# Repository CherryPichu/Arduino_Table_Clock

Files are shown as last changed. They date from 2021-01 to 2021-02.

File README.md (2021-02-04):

# Arduino_Table_Clock
아두이노 스마트 탁상시계 프로젝트 / Arduino Smart Desk Clock Project

** 강원FABLAB (한림대학교 산업협력단) Fab Lab Gangwon Making project - 디지털 장비를 활용한 메이킹 프로젝트

자취방 아이템 스마트 탁상시계  (1월 18일 ~ 1월 29일) 2주
------------------------------

**[유튜브 동영상](https://youtu.be/rYzuArcCpqY)**

아두이노 스마트 탁상시계 프로젝트 (https://youtu.be/rYzuArcCpqY)

<hr>
**작동 설명** 

자취방 혹은 기숙사에서 온도와 습도 그리고 조도 데이터를 눈으로 직접 확인하기 어렵다.

이 프로젝트는 거주공간에서 시계역활을 해주는 동시에 자취방 **온도, 습도, 조도** 데이터를 25초 간격으로 

**SD카드에 저장**하고 **API 서버**에 데이터를 보낸다.

이러한 데이터를 꾸준히 쌓아서 파이썬을 통해 **시각화를 거치면 거주 공간의 문제점을 파악할 수 있다.**

데이터는 SD카드와 인터넷 서버를 통해 이중으로 저장하는 만큼 어느 상황에서도 작동을 보장한다.

**기본 모드**

기본 모드

**기본 모드** 에서는 실시간으로 시간을 확인 할 수 있다.

별다른 조작이 없다면 기본 모드를 유지한다.

**상세 모드**

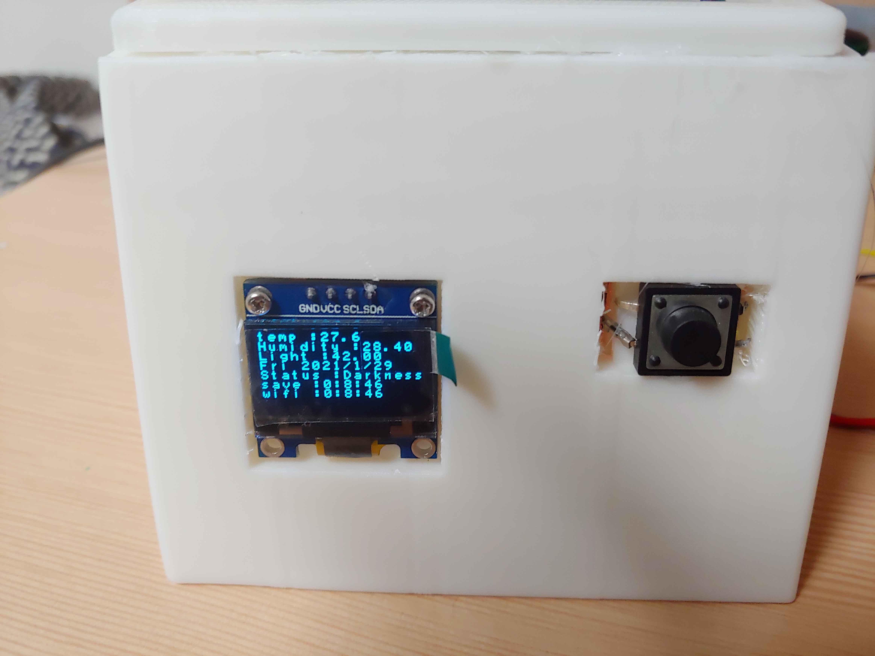
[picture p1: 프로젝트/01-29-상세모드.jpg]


상세 모드는 전면의 버튼을 클릭했을 때 4초간 보여준다.

상세 모드에서 보여줄 수 있는 정보은 하단의 내용과 같다.

\- temp : 현재 온도

\- Humidity : 현재 습도

\- 날짜

\- 현재 상태(빛) 5단계

 Very Bright – 매우 밝음

 Bright – 밝음

 Slight darkness – 약간 어두움

 Darkness – 어두움

 Very dark – 매우 어두움

\- save : 마지막 sd 저장 시간

\- wifi : 마지막 와이파이 저장 시간

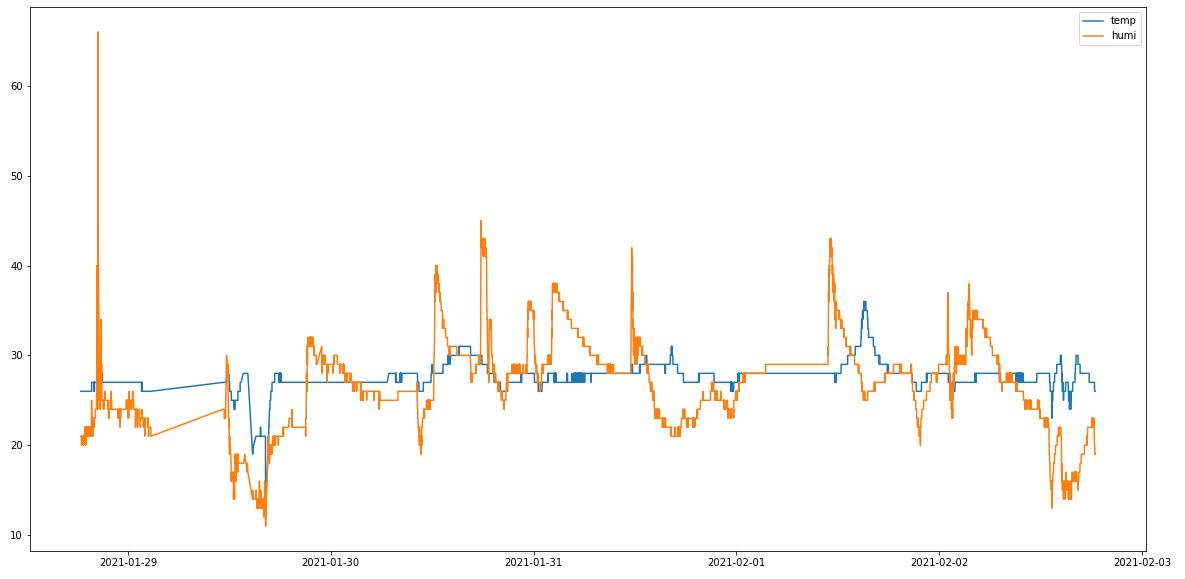
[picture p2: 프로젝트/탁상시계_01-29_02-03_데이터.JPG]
온습도 데이터


**[2021-01-29일~ 2021년 02월 03일 데이터 그래프 (온도 temp / 습도 humi)]**

실제로 저장받은 5일 동안의 데이터를 시각화를 시키면 알 수 있듯이.

습도와 온도는 상관 관계가 있다.

이는 생활 패턴과 관련이 있는데 화장실을 이용하고 문을 열어두면 굉장히 많은 습도가 방을 채운다.

또 동시에 온도가 높아지는 것을 확인할 수 있다.

창문을 열면은 추운 바람이 들어오면서 온도와 습도는 극격하게 내려가는 것을 확인할 수 있다.

습도는 20~35 사이로 적절한 습도를 유지하고 있음을 보여준다.(습도는 20 이하로 내려가지 않는 것이 좋다.)

상세 모드

**평균 온도**는 **27.5도**이고

**평균 습도**는 **27%** 이다.

데이터는 꾸준히 온라인과 SD카드에 저장되고 있다.

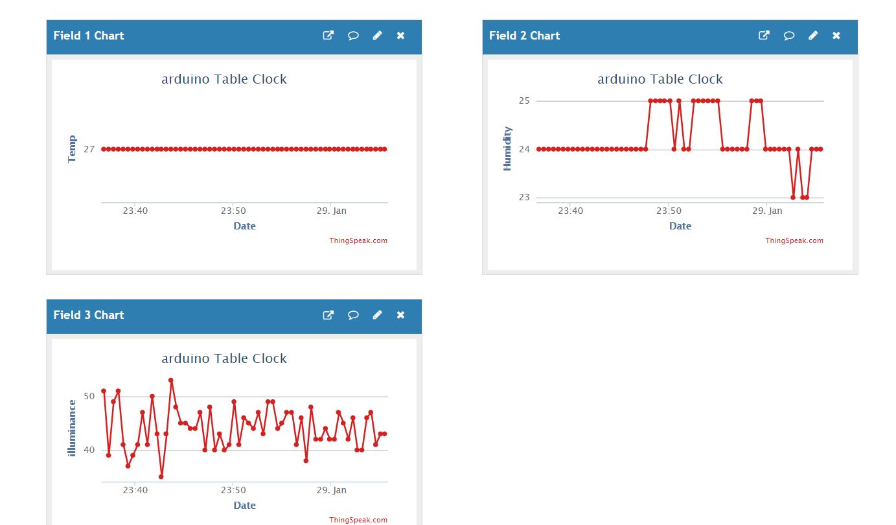
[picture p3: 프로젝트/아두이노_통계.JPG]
thingspeak.com


[thingspeak 온라인 데이터](https://thingspeak.com/channels/1291441)

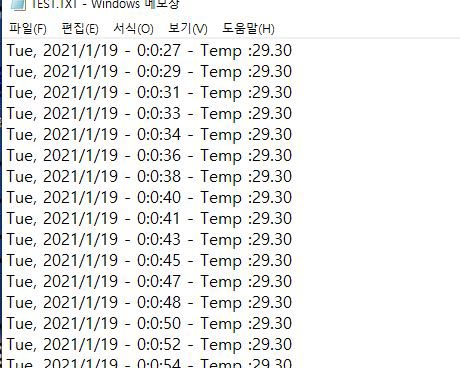
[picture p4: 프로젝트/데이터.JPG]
sd카드 저장 데이터


[SD카드 데이터]

마지막으로 프로젝트 후반에 추가된 조도 데이터는 사용자의 잠자는 시간과 패턴 등을 분석하기 좋다.

조도 데이터는 0(불빛 없음) ~ 1000 이상으로 데이터 편차가 크므로 log를 취해서 편차를 줄이면 조금더 유의미한 데이터를 얻을 수 있다.

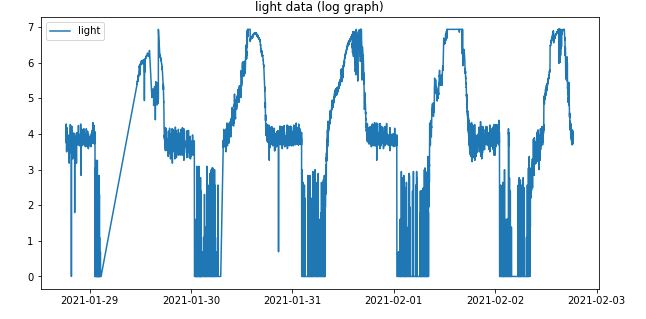
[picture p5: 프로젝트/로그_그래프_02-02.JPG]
조도 데이터


<hr>

- **내부 부품**

1. 아두이노 NANO 33 IOT
2. RTC DS3231 모듈
3. 0.96인치 128x64 OLED LCD 모듈
4. SD 카드 리더기 모듈
5. TEMT6000 조도 센서 모듈
6. [YwRobot] AM2302 (DHT22) 고정밀 온습도 센서 모듈

- 참고 사이트
  아두이노 Nano 33 IOT  
  https://fishpoint.tistory.com/5251
  RTC 모듈
  https://deneb21.tistory.com/327
  0.96인치 128x64 OLED LCD 모듈
  https://orasman.tistory.com/297

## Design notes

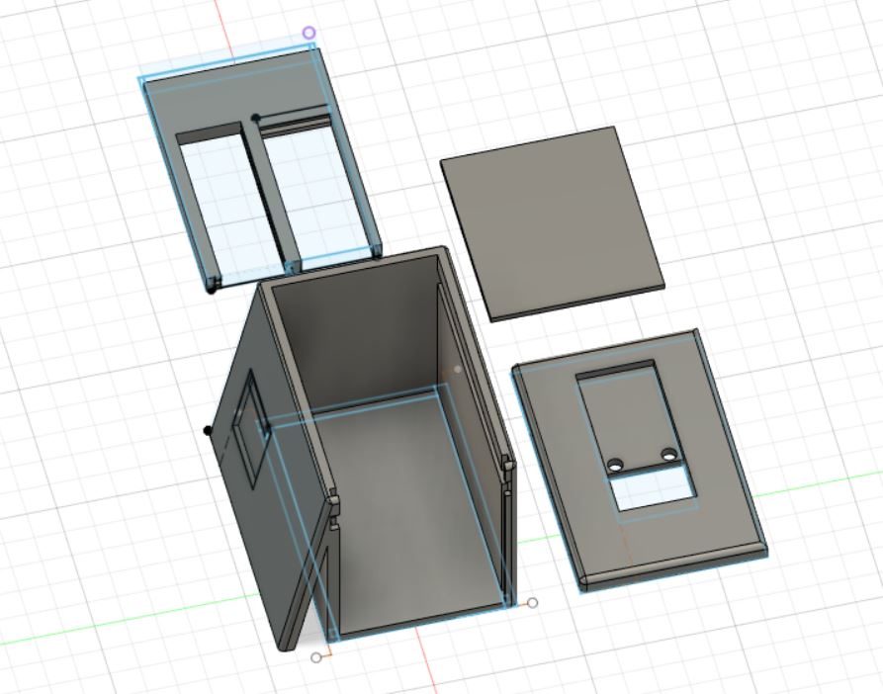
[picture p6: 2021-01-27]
프로젝트/21-01-22 모델링.JPG

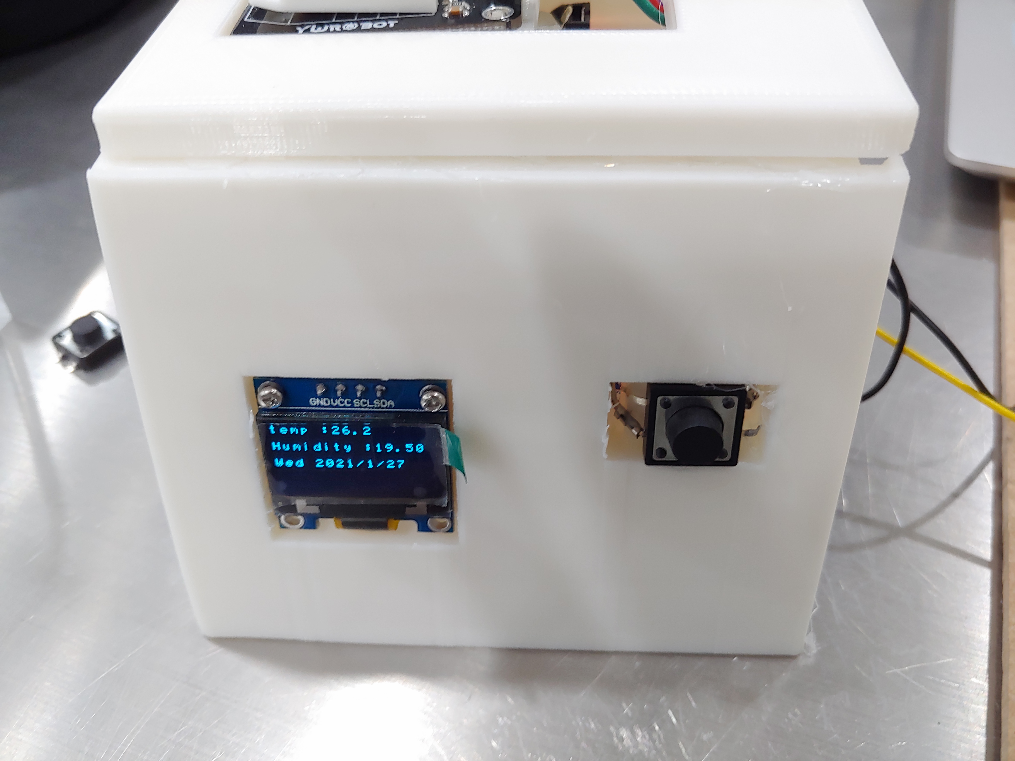
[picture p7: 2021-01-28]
프로젝트/01-27-탁상시계2.jpg

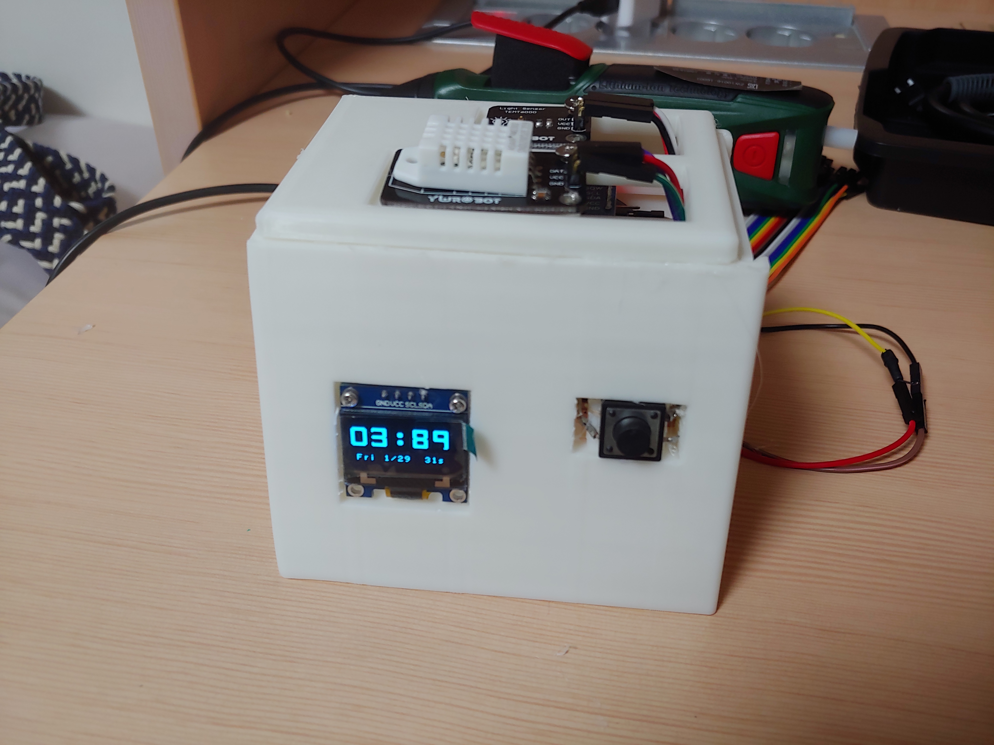
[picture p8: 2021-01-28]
프로젝트/01-29-기본-모드.jpg

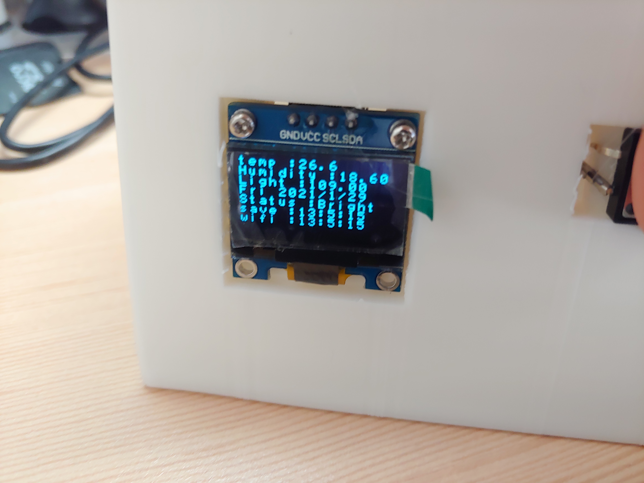
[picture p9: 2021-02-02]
프로젝트/화면.jpg

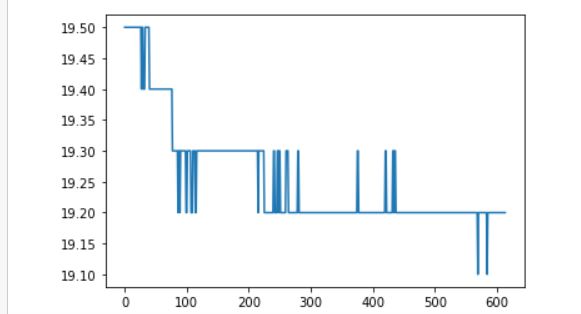
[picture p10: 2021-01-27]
프로젝트/온도 분석 _ 한림 메이커 스페이스 (10분).JPG

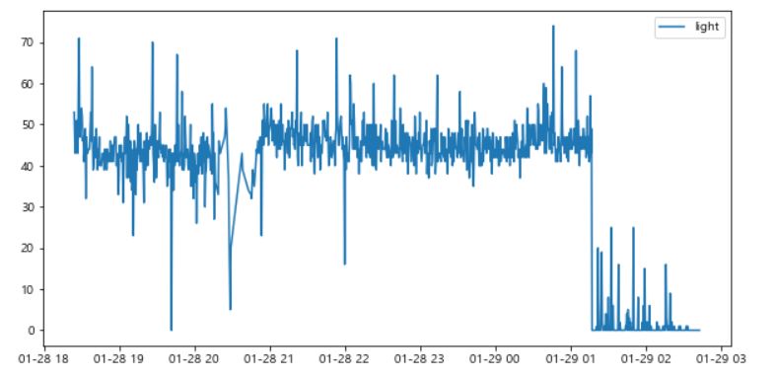
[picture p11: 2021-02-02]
프로젝트/light.JPG

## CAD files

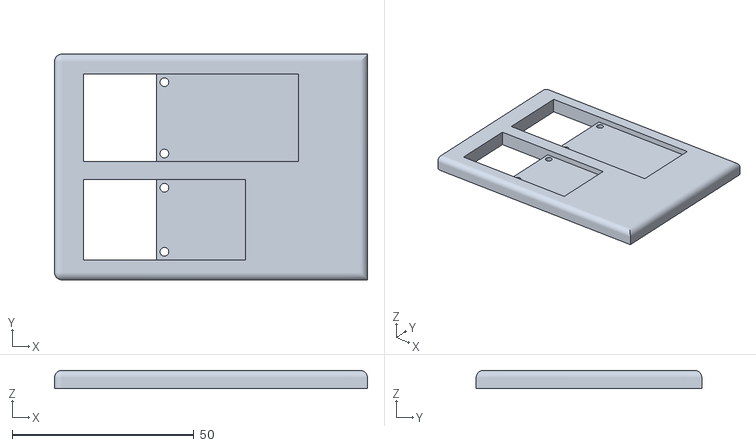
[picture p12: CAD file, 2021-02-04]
stl 파일/roof.stl
86.0 x 62.0 x 5.00

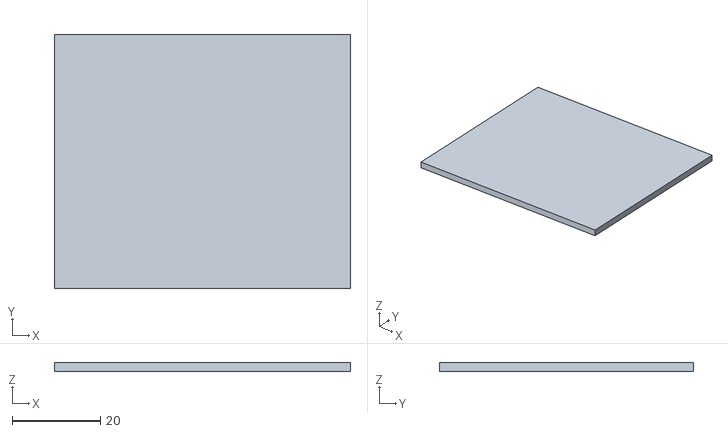
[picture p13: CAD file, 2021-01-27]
프로젝트/door.stl
67.0 x 57.6 x 2.00

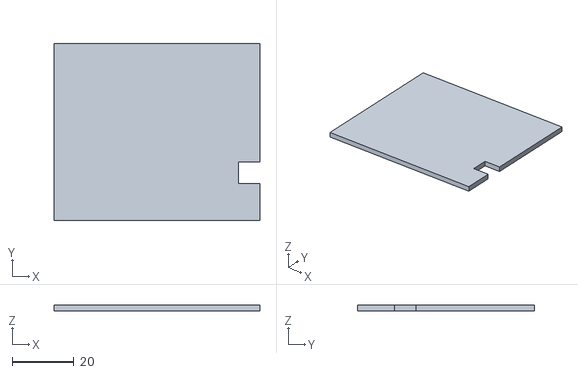
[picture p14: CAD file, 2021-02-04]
stl 파일/door.stl
67.0 x 57.6 x 2.00

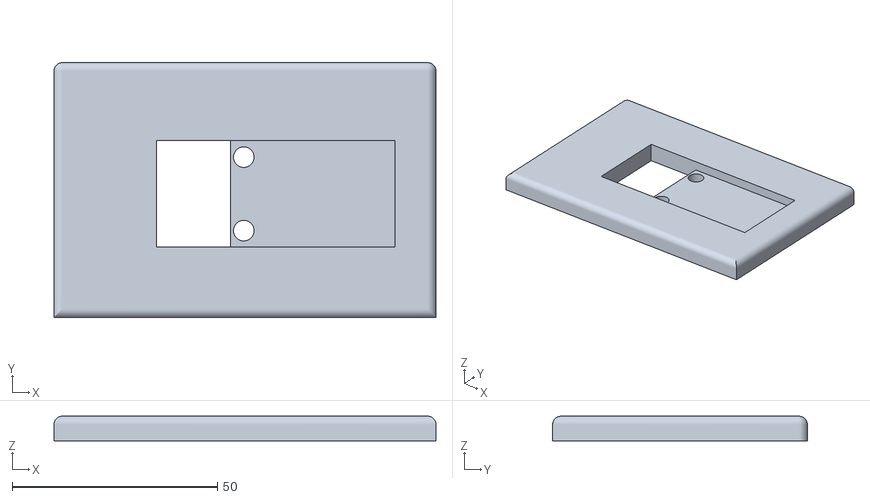
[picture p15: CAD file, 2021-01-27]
프로젝트/지붕.stl
93.0 x 62.0 x 6.00

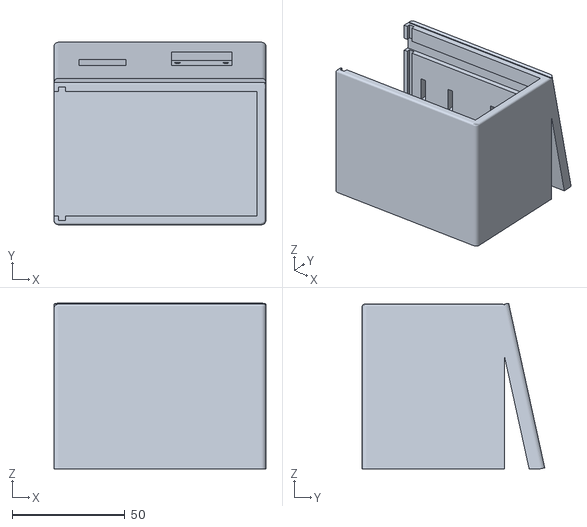
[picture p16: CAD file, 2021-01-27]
stl 파일/01_26_TABLE.stl
94.0 x 81.0 x 73.4

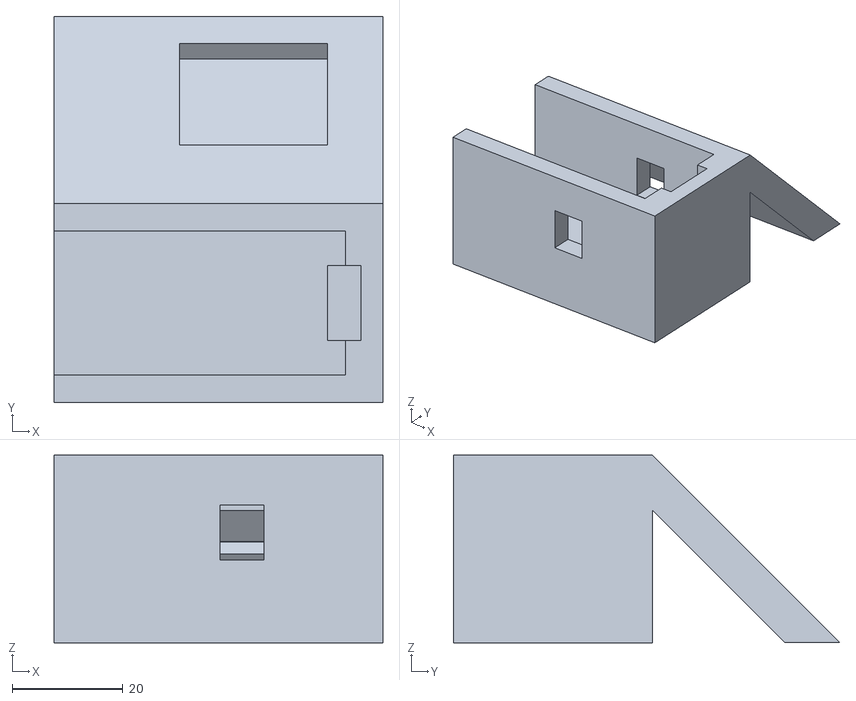
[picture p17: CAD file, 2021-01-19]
프로젝트/탁상시계_허남정.stl
59.5 x 69.9 x 34.0

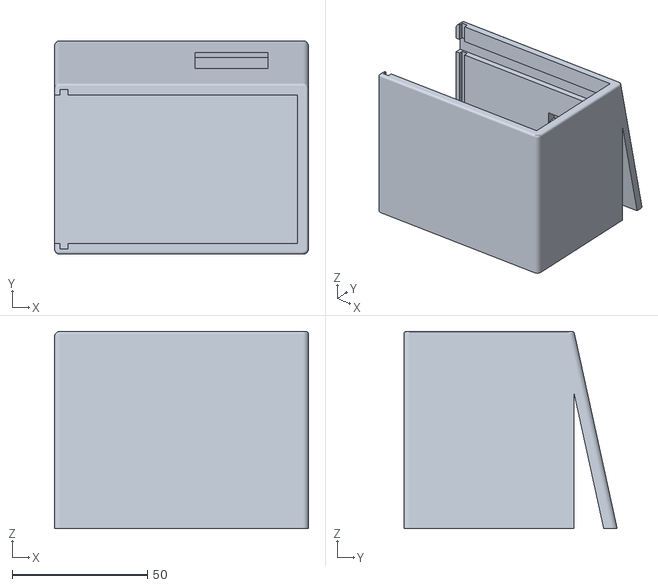
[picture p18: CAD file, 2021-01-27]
stl 파일/Table_clock.stl
94.0 x 79.0 x 73.0

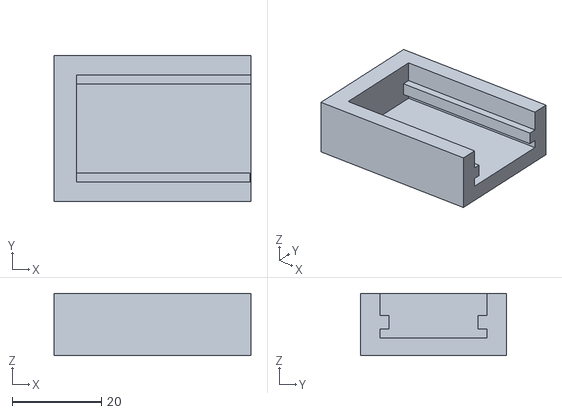
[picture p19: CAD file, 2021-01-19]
프로젝트/센서 케이스.stl
44.2 x 32.8 x 14.0

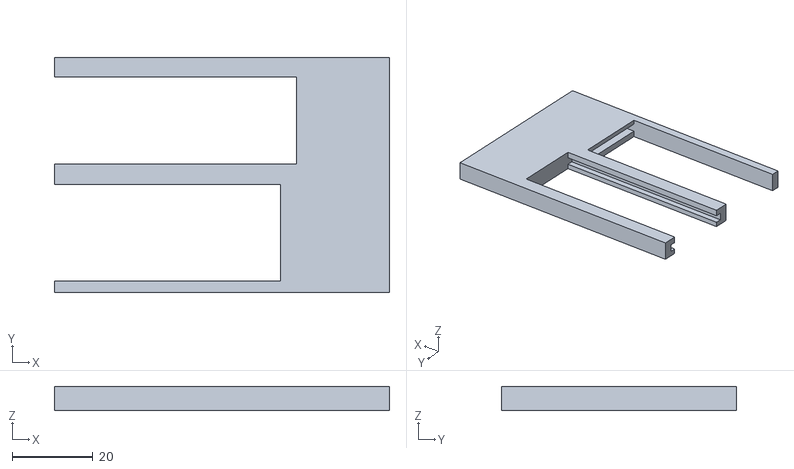
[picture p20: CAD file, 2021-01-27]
stl 파일/sensor.stl
83.0 x 58.2 x 6.00

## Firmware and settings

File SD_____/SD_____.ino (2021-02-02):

#include "DHT.h"
#include <SD.h>
#include <SPI.h>
#include <Wire.h>
#include <OzOLED.h>
#include <math.h>
#include <WiFiNINA.h>

int CS_PIN = 10;
int Sensor0 = 0;
String Data = "";
int count_down = 0; // sd카드 저장 주기 시간 계산해주는 변수(20)
int screen_change = 0; // 스크린 바뀔때 시간 세주는 변수
String last_save = ""; // 마지막으로 저장 시기
String last_wifi = ""; // 마지막으로 와이파이 통신시기

char ssid[] = "8-1324";        // your network SSID (name)  8-1324  Cherry
char pass[] = "";    // your network password (use for WPA, or use as key for WEP)
char server[] = "api.thingspeak.com";
int keyIndex = 0;
int status = WL_IDLE_STATUS; // wifi 추가
WiFiSSLClient client;

#define DHTPIN 2        // SDA 핀의 설정
#define DHTTYPE DHT22   // DHT22 (AM2302) 센서종류 설정
DHT dht(DHTPIN, DHTTYPE);

#include <Wire.h>
 
#define DS3231_I2C_ADDRESS 104
short seconds, minutes, hours, day, date, month, year;
char weekDay[4];
 
short tMSB, tLSB;
float temp3231;

File myFile;
#define LIGHTPIN A0 //Ambient light sensor reading
void setup() {
  
//  send_api();
  Serial.begin(115200); // 115200 9600
  delay(2000); // 버그 수정 딜레이를 줘야만 전원을 동시에 공급했을때 작동하는 듯?
  pinMode(4, OUTPUT); // 스위치(버튼)
  pinMode(5, INPUT_PULLUP);
  pinMode(LIGHTPIN, INPUT); //조도 센서
  OzOled.init();  //initialze Eduino OLED display
  OzOled.printString("Hello!");
  // put your setup code here, to run once:
  wifi_init();
  
  pinMode(CS_PIN, OUTPUT);
  dht.begin();
  Wire.begin();
  initalizeSD();
  OzOled.clearDisplay();
}

void initalizeSD(){
  Serial.println("Interalizing SD card..");
  pinMode(CS_PIN,OUTPUT);
  if(SD.begin()){
    Serial.println("SD Card is ready to use.");
  }else {
    Serial.println("SD Card initalization failed");
    OzOled.clearDisplay();
    OzOled.printString("SD Card", 0, 0);
    OzOled.printString("initalization failed", 0, 1);
    delay(3000);
    return;
  }
  return;
}
float get_light(){
  float reading = analogRead(LIGHTPIN); 
  return reading;
}
void wifi_init(){ // wifi 추가
  if (WiFi.status() == WL_NO_MODULE) {
    Serial.println("Communication with WiFi module failed!");
    OzOled.printString("Communication with WiFi module failed!", 0,1);
    // don't continue
    while (true);
  }
  while (status != WL_CONNECTED) {
    Serial.print("Attempting to connect to SSID: ");
    OzOled.printString("Attempting to connect to SSID: ",0,2);
    Serial.println(ssid);
    // Connect to WPA/WPA2 network. Change this line if using open or WEP network:
    status = WiFi.begin(ssid, pass);

    // wait 10 seconds for connection:
    delay(10000);
  }
  Serial.println("Connected to wifi");
  OzOled.printString("Connected to wifi",0,4);
  printWiFiStatus();
   String fv = WiFi.firmwareVersion();
    if (fv < WIFI_FIRMWARE_LATEST_VERSION) {
    Serial.println("Please upgrade the firmware");
  }
  Serial.println("\nStarting connection to server...");
  OzOled.printString("Starting connection to server...",0,5);
  // if you get a connection, report back via serial:
  OzOled.clearDisplay();
}
void send_api(int temp, int humidity, float light) { // wifi 추가

  if (client.connect(server, 443)) {
    Serial.println("connected to server");
//    OzOled.printString("connected to server",0,6);
    // Make a HTTP request:
    client.println("GET /update?api_key=I1IPO6UY6WQG4IN8&field1="+String(temp)+"&field2="+String(humidity)+"&field3=" + String(light));
    client.println("Host: api.thingspeak.com");
    client.println("Connection: close");
    client.println();
    last_wifi = String(hours) + ":" +String(minutes) + ":" + String(seconds);
  }
}
void TestWiFiConnection()
//test if always connected
{
 int StatusWiFi=WiFi.status();
 if(StatusWiFi==WL_CONNECTION_LOST || StatusWiFi==WL_DISCONNECTED || StatusWiFi==WL_SCAN_COMPLETED) //if no connection
 {
  WiFi.end(); // WiFi를 종료한다.
  WiFiConnect(); //if my SSID is present, connect
 }
}
void WiFiConnect()
//connect to my SSID
{
 status= WL_IDLE_STATUS;
 while(status!=WL_CONNECTED)
 {
    OzOled.printString("try to connect..",1, 0, 15);
   status = WiFi.begin(ssid,pass);
   delay(2000);
  }
  OzOled.printString("               ",1, 0, 20);
}


void loop() {
  float light  = get_light();
  float humidity = dht.readHumidity();
  float temp = dht.readTemperature();
  String light_status = "";
  if(light > 140) {
      light_status = "Very bright"; 
    }else if(light > 80 && light <= 140) {
      light_status = "Bright"; 
    }else if(light > 60 && light <= 80) {
      light_status = "Slight darkness";
    }else if(light > 30 && light <= 60) {
      light_status = "Darkness";
    }else if(light > 0 && light <= 30) {
      light_status = "Very dark";
    }
   TestWiFiConnection();
  // put your main code here, to run repeatedly:
  watchConsole();
  get3231Date();
  Data =  String(weekDay) + ", 20" + String(year) + "/" + String(month) + "/" + String(date) + "," + String(hours) + ":" + String(minutes) + ":" + 
       String(seconds) + " , Temp :" + String(temp) + " , Humidity :" + String(humidity)+", light :" + String(light);
  if(count_down == 20){
  //("20" + String(year) + "/" + String(month)+"/"+String(date) +"-info")
      String file_name = String(month)+"M"+String(date)+"D.txt";
      Serial.println(file_name);
      myFile = SD.open(file_name, FILE_WRITE);
      send_api(temp, humidity, light);
      if(myFile){
        Serial.println("File created successfully");
        last_save = String(hours) + ":" +String(minutes) + ":" + String(seconds);
      }else {
        Serial.println("Error while creating file.");
        OzOled.clearDisplay();
        OzOled.printString("Error while", 0, 0);
        OzOled.printString("creating file", 0, 1);
        delay(2000);
        OzOled.clearDisplay();
      }
    myFile.println(Data);
    myFile.close();
    count_down = 0;
  }else{
    count_down++;
  }
  
  
  Serial.println(Data);
  // 아래 코드는 기본 화면 구성 출력
  if(digitalRead(5) == LOW){ // 스위치가 눌렸을 경우
    screen_change = 5;
    OzOled.clearDisplay();
  }
  if(screen_change > 1){ // 버튼이 눌린 경우에 온도와 습도창을 보여준다.
    OzOled.printString(("temp :"+String(temp,2)).c_str(), 0 ,0,10);
    OzOled.printString(("Humidity :" + String(humidity,2)).c_str(), 0 ,1,16);
    OzOled.printString(("Light :" + String(light, 2)).c_str(), 0 ,2,16);
    OzOled.printString((String(weekDay)+" "+ "20" + String(year) + "/" + String(month)+"/"+String(date)).c_str(), 0 ,3,16);
    OzOled.printString(("Status :" + light_status).c_str(), 0 ,4,16);
    OzOled.printString(("save :" + last_save).c_str(), 0 ,5,16);
    OzOled.printString(("wifi :" + last_wifi).c_str(), 0 ,6,16);
    screen_change--;
    if(screen_change == 1){
      screen_change = 0;
      OzOled.clearDisplay();
    }
  }else{
    String str_hours = String(hours);
    String str_minutes = String(minutes);
    String str_seconds = String(seconds) + "s ";
    const char * time_hours = str_hours.c_str(); // 한글 출력 방법
    const char * time_minutes = str_minutes.c_str(); 
    const char * time_seconds = str_seconds.c_str(); 
    
    OzOled.printBigNumber(time_hours, 0, 1,3);
    OzOled.printBigNumber(":",6,1, 10);
    OzOled.printBigNumber(time_minutes, 9, 1,3);
    OzOled.printString(time_seconds,11,6, 3); //x위치 y위치 글자 수
    
    OzOled.printString((String(weekDay)+" "+ String(month)+"/"+String(date)).c_str(),1,6, 10); 

  }
  


  
  delay(1000);
}


// 10진수를 2진화 10진수인 BCD 로 변환 (Binary Coded Decimal)
short decToBcd(short val)
{
  return ( (val/10*16) + (val%10) );
}
 
void watchConsole()
{
  if (Serial.available()) {      // Look for char in serial queue and process if found
    if (Serial.read() == 84) {   //If command = "T" Set Date
//      set3231Date();
      get3231Date();
      Serial.println(" ");
    }
  }
}
 
//시간설정
// T(설정명령) + 년(00~99) + 월(01~12) + 일(01~31) + 시(00~23) + 분(00~59) + 초(00~59) + 요일(1~7, 일1 월2 화3 수4 목5 금6 토7)
// 예: T1605091300002 (2016년 5월 9일 13시 00분 00초 월요일)
void set3231Date()
{
  year    = (short) ((Serial.read() - 48) *10 +  (Serial.read() - 48));
  month   = (short) ((Serial.read() - 48) *10 +  (Serial.read() - 48));
  date    = (short) ((Serial.read() - 48) *10 +  (Serial.read() - 48));
  hours   = (short) ((Serial.read() - 48) *10 +  (Serial.read() - 48));
  minutes = (short) ((Serial.read() - 48) *10 +  (Serial.read() - 48));
  seconds = (short) ((Serial.read() - 48) * 10 + (Serial.read() - 48));
  day     = (short) (Serial.read() - 48);
 
  Wire.beginTransmission(DS3231_I2C_ADDRESS);
  Wire.write(0x00);
  Wire.write(decToBcd(seconds));
  Wire.write(decToBcd(minutes));
  Wire.write(decToBcd(hours));
  Wire.write(decToBcd(day));
  Wire.write(decToBcd(date));
  Wire.write(decToBcd(month));
  Wire.write(decToBcd(year));
  Wire.endTransmission();
}
 
 
void get3231Date()
{
  // send request to receive data starting at register 0
  Wire.beginTransmission(DS3231_I2C_ADDRESS); // 104 is DS3231 device address
  Wire.write(0x00); // start at register 0
  Wire.endTransmission();
  Wire.requestFrom(DS3231_I2C_ADDRESS, 7); // request seven shorts
 
  if(Wire.available()) {
    seconds = Wire.read(); // get seconds
    minutes = Wire.read(); // get minutes
    hours   = Wire.read();   // get hours
    day     = Wire.read();
    date    = Wire.read();
    month   = Wire.read(); //temp month
    year    = Wire.read();
       
    seconds = (((seconds & B11110000)>>4)*10 + (seconds & B00001111)); // convert BCD to decimal
    minutes = (((minutes & B11110000)>>4)*10 + (minutes & B00001111)); // convert BCD to decimal
    hours   = (((hours & B00110000)>>4)*10 + (hours & B00001111)); // convert BCD to decimal (assume 24 hour mode)
    day     = (day & B00000111); // 1-7
    date    = (((date & B00110000)>>4)*10 + (date & B00001111)); // 1-31
    month   = (((month & B00010000)>>4)*10 + (month & B00001111)); //msb7 is century overflow
    year    = (((year & B11110000)>>4)*10 + (year & B00001111));
  }
  else {
    //oh noes, no data!
  }
 
  switch (day) {
    case 1:
      strcpy(weekDay, "Sun");
      break;
    case 2:
      strcpy(weekDay, "Mon");
      break;
    case 3:
      strcpy(weekDay, "Tue");
      break;
    case 4:
      strcpy(weekDay, "Wed");
      break;
    case 5:
      strcpy(weekDay, "Thu");
      break;
    case 6:
      strcpy(weekDay, "Fri");
      break;
    case 7:
      strcpy(weekDay, "Sat");
      break;
  }
}
 
//float get3231Temp()
//{
//  //temp registers (11h-12h) get updated automatically every 64s
//  Wire.beginTransmission(DS3231_I2C_ADDRESS);
//  Wire.write(0x11);
//  Wire.endTransmission();
//  Wire.requestFrom(DS3231_I2C_ADDRESS, 2);
// 
//  if(Wire.available()) {
//    tMSB = Wire.read(); //2's complement int portion
//    tLSB = Wire.read(); //fraction portion
//   
//    temp3231 = (tMSB & B01111111); //do 2's math on Tmsb
//    temp3231 += ( (tLSB >> 6) * 0.25 ); //only care about bits 7 & 8
//  }
//  else {
//    //error! no data!
//  }
//  return temp3231;
//}

void printWiFiStatus() { // wifi 추가 부분
  // print the SSID of the network you're attached to:
  Serial.print("SSID: ");
  Serial.println(WiFi.SSID());

  // print your board's IP address:
  IPAddress ip = WiFi.localIP();
  Serial.print("IP Address: ");
  Serial.println(ip);

  // print the received signal strength:
  long rssi = WiFi.RSSI();
  Serial.print("signal strength (RSSI):");
  Serial.print(rssi);
  Serial.println(" dBm");
}

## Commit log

2021-01-27 시계 ui계선 버튼 조작 추가 sd카드 저장주기20초
    [Table_clock.stl, door.stl, namjung_table_clock_01_25.stl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]
2021-01-27 wifi 기능 추가 주기적으로 업데이트
2021-01-28 프로젝트 마지막 업데이트
2021-02-02 Read me 업데이트: 프로젝트 설명 추가
2021-02-02 read me 업데이트 수정
2021-02-02 git 허브 이미지 이름에 화이트 스페이스바가 있으면 read me에 안뜨는 문제 수정
2021-02-02 동영상 업데이트 테스트
2021-02-02 유튜브 재 업로드
2021-02-04 stl 파일 업로드
    [01_26_TABLE.stl, Table_clock.stl, door.stl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]
2021-02-04 사진 버그 수정;;
